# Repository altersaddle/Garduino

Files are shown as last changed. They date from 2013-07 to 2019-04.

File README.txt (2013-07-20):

The purpose of this project is to enable data collection and eventually action to keep
plants alive in a garden.

This project encompasses five components:

1) The "Garduino" device itself, which manages the sensors and external controls

2) The Arduino software that's running on the device

3) A serial monitor that accepts serial (via bluetooth) data from the Garduino

4) A database to keep all of the data

5) A reporting application / system to let users manage the data

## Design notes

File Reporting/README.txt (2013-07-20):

The current design for reporting will be a website generated by a scheduled task.

Chart.js will provide graphs for the report.

The resulting data can be uploaded periodically to a remote web host for review.

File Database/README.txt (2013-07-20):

This system uses a Microsoft SQL Server instance (SQL Express) to store data.

Any other database with a connection for .NET may also be used.

For now, very little database functionality is required.  Data is assigned a timestamp as it
is collected / inserted.

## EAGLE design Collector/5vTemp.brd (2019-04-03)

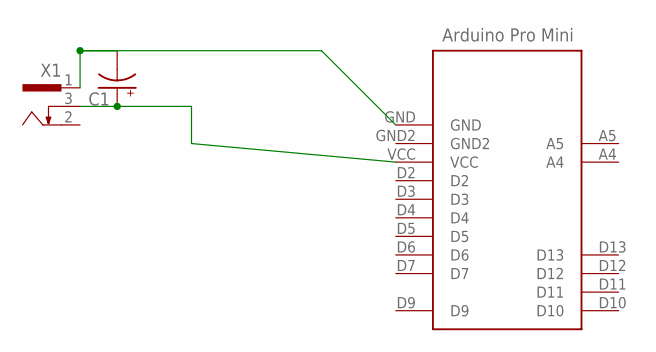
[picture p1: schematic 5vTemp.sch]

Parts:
C1: CPOL-USSANYO_C; SANYO-OSCON_C
U$1: ARDUINO_PRO_MINI_5V_V2V2; ARDUINO_PRO_MINI_5V_V2
X1: 733980-62

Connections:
unnamed: C1.+, U$1.VCC, X1.3
unnamed: C1.-, U$1.GND, X1.1

Board: 2 copper layers, 3 parts (0 on the bottom side), 2 nets, no tracks yet.

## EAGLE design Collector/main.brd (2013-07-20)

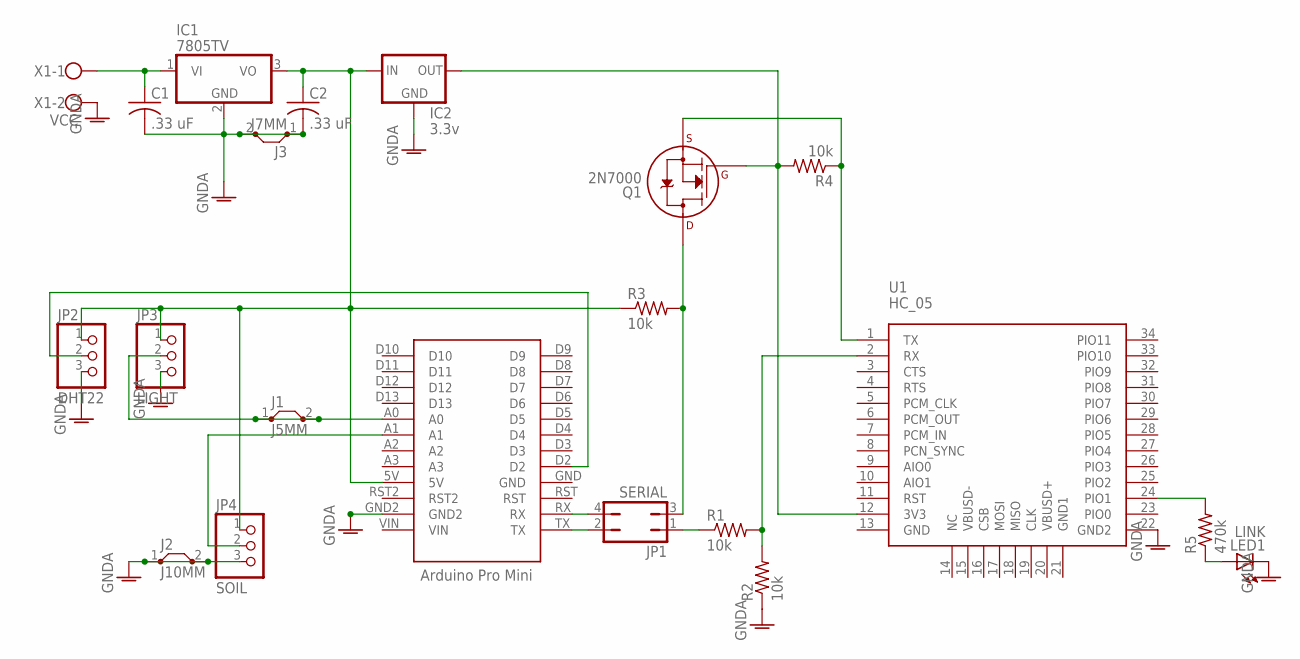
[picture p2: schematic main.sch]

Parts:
C1, C2: .33 uF; C025-050X050
IC1: 7805TV; TO220V
IC2: 3.3v; TO92-INLINE
J1: J5MM; 05
J2: J10MM; 10
J3: J7MM; 07
JP1: SERIAL; JP2Q
JP2: DHT22; 1X03
JP3: LIGHT; 1X03
JP4: SOIL; 1X03
LED1: LINK; LED3MM
Q1: 2N7000; TO-92
R1, R2, R3, R4: 10k; 0204/7
R5: 470k; 0204/7
U1: HC_05; BLUETOOTH_SMD
U$1: ARDUINO_PRO_MINI_5V_V1V1; ARDUINO_PRO_MINI_5V_V1
X1: VCC; W237-102

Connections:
GNDA: C1.2, C2.2, IC1.2 (GND), IC2.1 (GND), J2.1, J2.2, J3.1, J3.2, JP2.3, JP3.3, JP4.3, LED1.K (C), R2.1, U1.22 (GND2), U$1.GND2, X1.2
unnamed: IC2.3 (OUT), Q1.2 (G), R4.2, U1.12 (3V3)
unnamed: JP1.2, U$1.TX
unnamed: R1.2, R2.2, U1.2 (RX)
unnamed: C1.1, IC1.1 (VI), X1.1
unnamed: JP1.3, Q1.3 (D), R3.2
unnamed: Q1.1 (S), R4.1, U1.1 (TX)
unnamed: JP1.1, R1.1
unnamed: JP1.4, U$1.RX
unnamed: LED1.A, R5.1
unnamed: R5.2, U1.24 (PIO1)
unnamed: C2.1, IC1.3 (VO), IC2.2 (IN), JP2.1, JP3.1, JP4.1, R3.1, U$1.5V
unnamed: J1.1, J1.2, JP3.2, U$1.A0
unnamed: JP4.2, U$1.A1
unnamed: JP2.2, U$1.D2

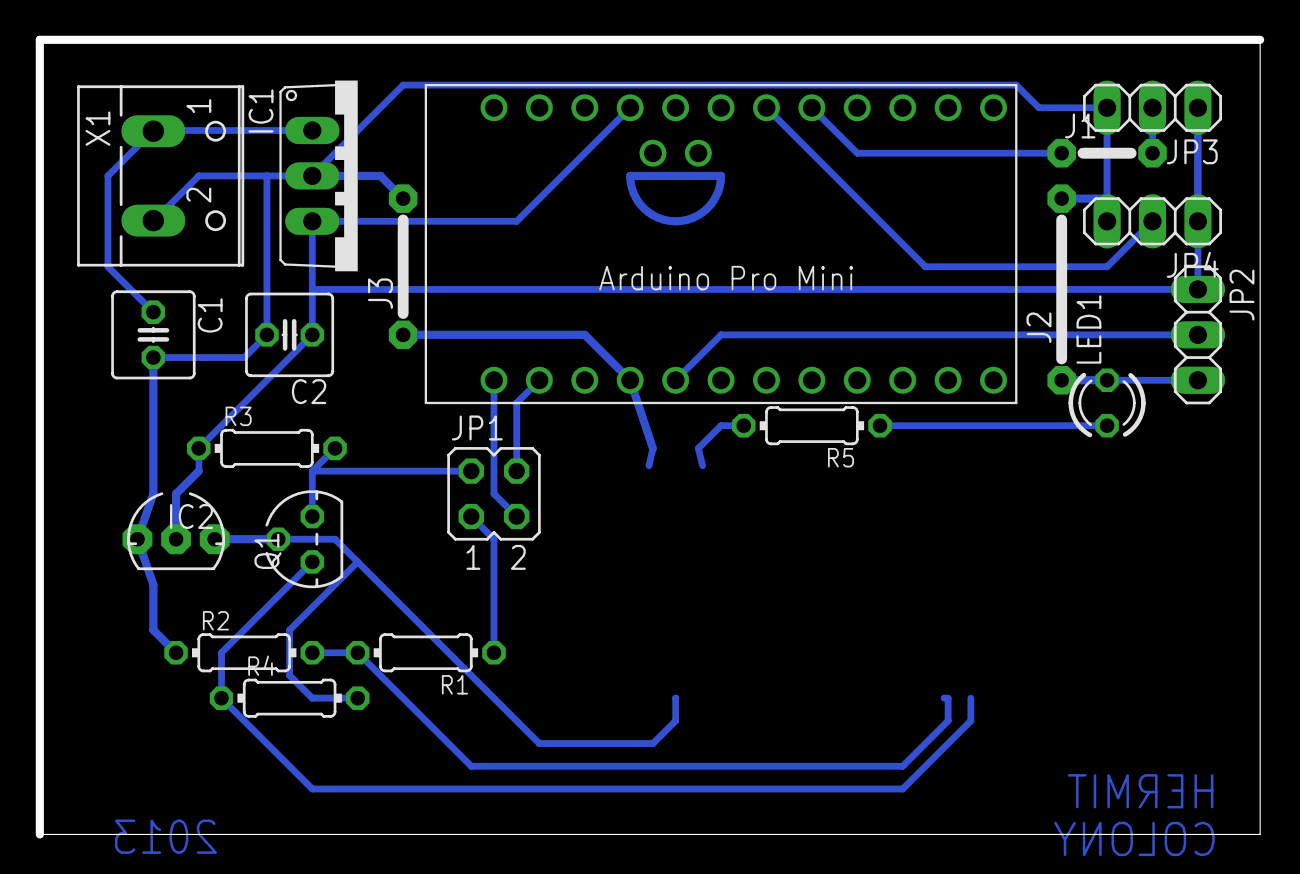
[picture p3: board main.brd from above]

Board: 2 copper layers, 68.2 x 44.4 mm, 21 parts (1 on the bottom side), 15 nets.

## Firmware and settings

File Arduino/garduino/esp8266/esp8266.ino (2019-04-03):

#include <ESP8266WiFi.h>
#include <ESP8266WiFiAP.h>
#include <ESP8266WiFiGeneric.h>
#include <ESP8266WiFiMulti.h>
#include <ESP8266WiFiScan.h>
#include <ESP8266WiFiSTA.h>
#include <ESP8266WiFiType.h>
#include <WiFiClient.h>
#include <WiFiClientSecure.h>
#include <WiFiServer.h>
#include <WiFiUdp.h>

#include <SimpleDHT.h>

// for DHT11, 
//      VCC: 5V or 3V
//      GND: GND
//      DATA: 2
int pinDHT11 = 0;
SimpleDHT11 dht11;

const char* ssid = "wifi-ssid";
const char* password = "password";

const char* emonHost = "emonhost";
const char* emonKey = "emonkey";

// addresses of interest - might be better to use DHCP here if possible
IPAddress staticIP(192,168,1,110);
IPAddress gateway(192,168,1,1);
IPAddress subnet(255,255,255,0);

WiFiClient client;

void setup() {
  Serial.begin(115200);

  // Connecting to WiFi network
  Serial.println();
  Serial.print("Connecting to ");
  Serial.println(ssid);

  WiFi.config(staticIP, gateway, subnet);
  WiFi.begin(ssid, password);
  
  while (WiFi.status() != WL_CONNECTED) {
    delay(500);
    Serial.print(".");
  }
  Serial.println("");
  Serial.print("WiFi connected: ");
  Serial.println(WiFi.localIP());

}

void loop() {
  // start working...
  Serial.println("=================================");
  Serial.println("Sample DHT11...");
  
  // read without samples.
  byte temperature = 0;
  byte humidity = 0;
  if (dht11.read(pinDHT11, &temperature, &humidity, NULL)) {
    Serial.print("Read DHT11 failed.");
    delay(1000);
    return;
  }
  
  Serial.print("Sample OK: ");
  Serial.print((int)temperature); Serial.print(" *C, "); 
  Serial.print((int)humidity); Serial.println(" %");

  // Upload to emonCMS
  // /emoncms/input/post.json?node=1&json={power1:100,power2:200,power3:300}
  String url = "/emoncms/input/post.json?node=1&json={dht11_temp:";
  request(emonHost, 80, url + (int)temperature + ",dht11_humid:" + (int)humidity + "}&apikey=" + emonKey);
  
  // DHT11 sampling rate is 1HZ.
  // Wait five seconds before retrying
  delay(5000);
}

bool request(const char * host, int port, String url) {
  if ( !client.connect(host, port) ) {
    return false;
  }
      // Make an HTTP GET request
  client.println("GET " + url + " HTTP/1.1");
  client.print("Host: ");
  client.println(host);
  client.println("Connection: close");
  client.println();
  
  return true;
}

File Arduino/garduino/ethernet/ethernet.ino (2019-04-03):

#include <UIPEthernet.h>
#include <SimpleDHT.h>


// for DHT11, 
//      VCC: 5V or 3V
//      GND: GND
//      DATA: 2
int pinDHT11 = 2;
SimpleDHT11 dht11;

const char* emonHost = "emonhost"; // update to suit your environment
const char* emonKey = "emonkey";   // use write keys from emoncms

const static uint8_t myip[] = {192,168,1,111};
const static uint8_t mygw[] = {192,168,1,1};
//const static uint8_t mymask[] = {255,255,255,0};
const static uint8_t mydns[] = {192,168,1,1};

// Ha ha yes!  We can invent our own MAC
static uint8_t mac[] = {0x74,0x69,0x69,0x2D,0x30,0x31};

EthernetClient client;
signed long next;
signed long wait;

void setup() {
  Serial.begin(115200);
  Serial.println("Ethernet based temperature monitor");

  Ethernet.begin(mac, myip, mydns, mygw);

  Serial.print(F("localIP: "));
  Serial.println(Ethernet.localIP());
  Serial.print(F("subnetMask: "));
  Serial.println(Ethernet.subnetMask());
  Serial.print(F("gatewayIP: "));
  Serial.println(Ethernet.gatewayIP());
  Serial.print(F("dnsServerIP: "));
  Serial.println(Ethernet.dnsServerIP());

  wait = (30 * 60000) - 500;
}

void loop() {
  Serial.print(F("Sample DHT11..."));
  
  // read without samples.
  byte temperature = 0;
  byte humidity = 0;
  if (dht11.read(pinDHT11, &temperature, &humidity, NULL)) {
    Serial.println(F("failed."));
    delay(5000);
    return;
  }
  
  Serial.print(F("OK: "));
  Serial.print((int)temperature); Serial.print(F(" C, ")); 
  Serial.print((int)humidity); Serial.println(F(" %"));

  // Upload to emonCMS
  // /emoncms/input/post.json?node=1&json={power1:100,power2:200,power3:300}
  String args = String(F("?node=2&json=%7Bdht11_temp:")) + (int)temperature + F(",dht11_humid:") + (int)humidity + F("%7D&apikey=");
  request(emonHost, "/emoncms/input/post.json", args, emonKey );
  Ethernet.maintain();
    
  // DHT11 sampling rate is 1HZ.
  // Wait 5 seconds before retrying
  delay(wait);
}

void request(const char * host, char * path, String args, const char * key) {
  next = millis() + 5000;
  if (client.connect(emonHost, 80)) {
    client.print(F("GET "));
    client.print(path);
    client.print(args);
    client.print(key);
    client.print(F(" HTTP/1.0\r\n"));
    Ethernet.maintain();
    client.print(F("Host: "));
    client.print(host);
    client.print(F("\r\nConnection: close\r\n\r\n"));
    while(client.available()==0)
    {
      if (next - millis() < 0)
        goto close;
    }
    int size;
   /* while((size = client.available()) > 0)
    {
      uint8_t* msg = (uint8_t*)malloc(size);
      size = client.read(msg,size);
      Serial.write(msg,size);
      free(msg);
    }*/
    close:
          //disconnect client
          Serial.println(F("sent message"));
          //client.stop();
  }
  else {
     Serial.println(F("connect failed"));
  }
}

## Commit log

2013-07-20 Initial import
    The files that we have so far.
    [DRILEGEND.CFG, main.brd, main.sch]
2013-07-20 Inserting into a database
2013-07-20 Apparently arduino needs the files this way
2013-07-22 working sample data!
2013-08-10 add index to sensor table, reduce query times
2013-08-11 add graph for light sensor
2013-11-15 Arduino simulator app
2019-04-03 EAGLE files for Collector
    EAGLE files for 5v powered temp monitor
    [5vTemp.brd, 5vTemp.sch]
2019-04-03 Adding emoncms collector prototypes
